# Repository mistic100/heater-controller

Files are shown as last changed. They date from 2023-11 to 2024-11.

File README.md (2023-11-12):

# heater controller

This is controller for electric heater with a control wire, widespread in France (Europe ?).



Inspired by [Jérôme Labidurie work](http://dinask.eu/hardware/filpilote/).

It can control two separate electric heaters with four orders (Confort, Éco, Hors gel, Arrêt) and one electric water tank (via controllable circuit beaker). It connects to your WiFi and has a nice web interface.

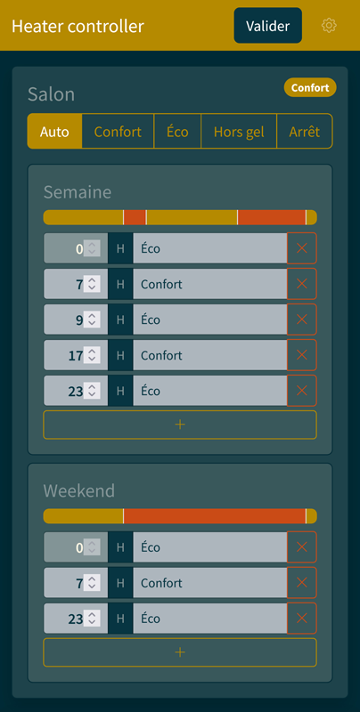
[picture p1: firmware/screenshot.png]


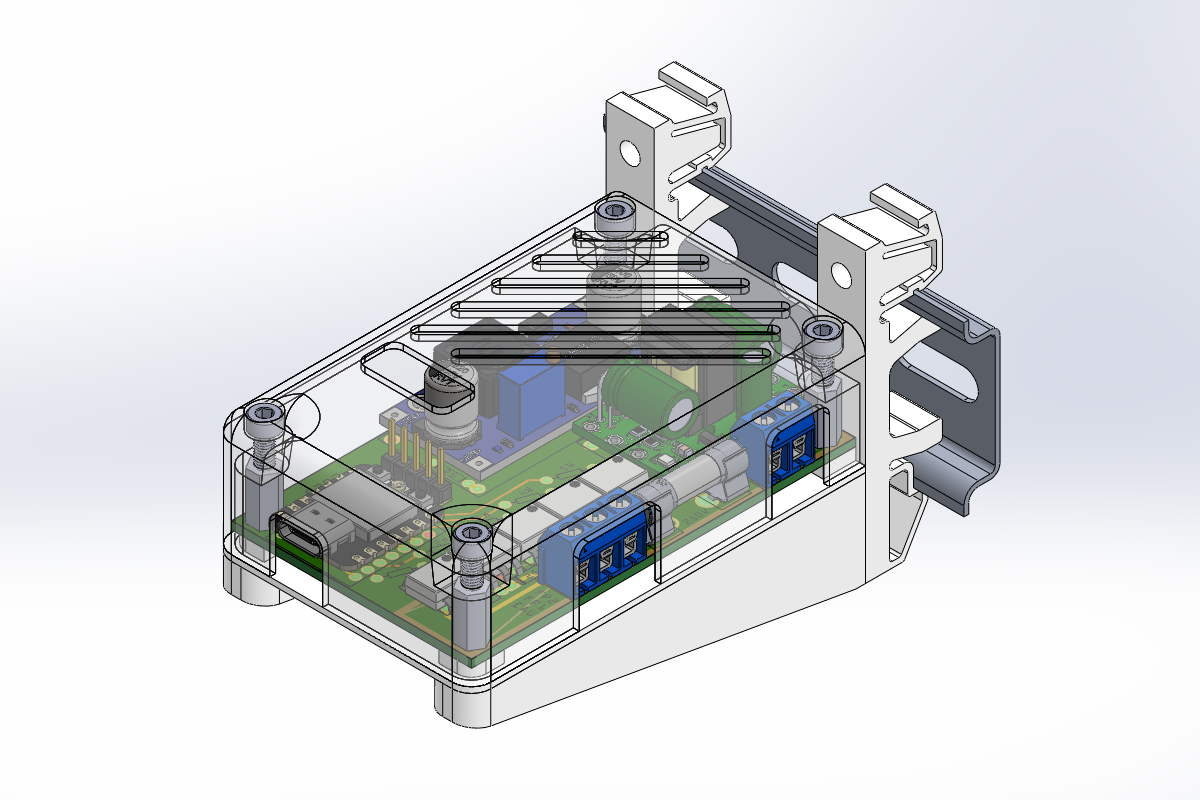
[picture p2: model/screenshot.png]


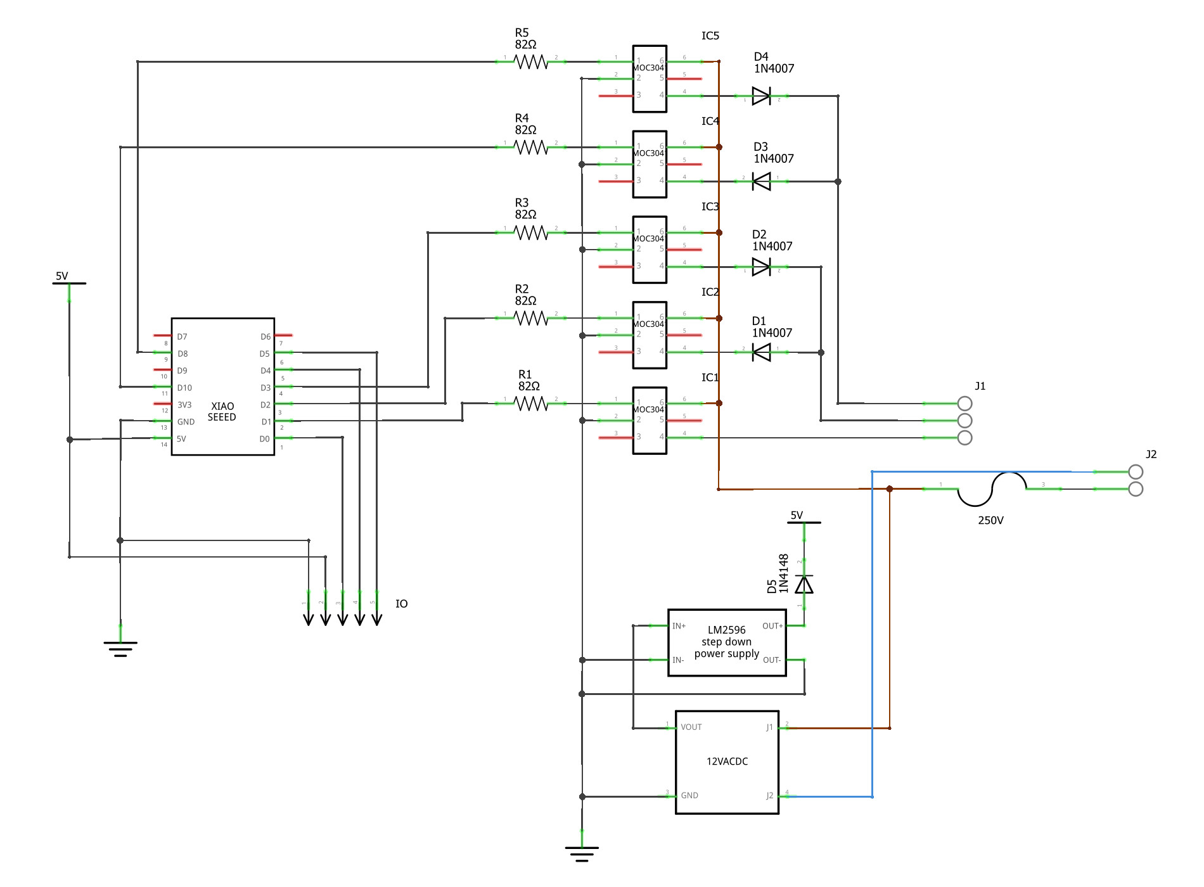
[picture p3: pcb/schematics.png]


## Hardware

- Seeduino Xiao ESP32C3
- mini 12V AC/DC converter
- LM2596 step down regulator
- 5x MOC3041 triac driver
- 4x 1N4007 diode
- 1x 1N4148 diode
- 5x resistors
- 250V fuse
- terminals
- M3 screws, spacers and heated inserts
- 3D printed case

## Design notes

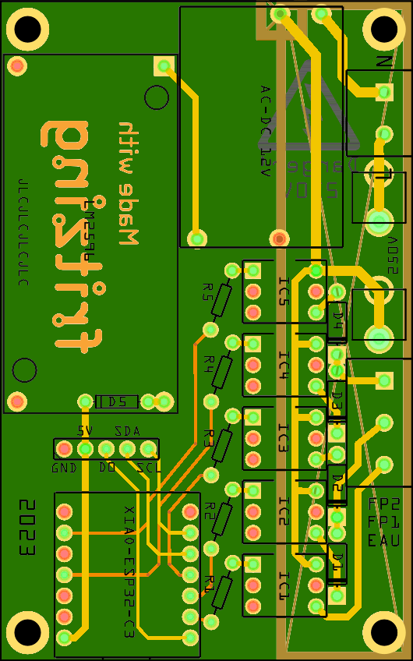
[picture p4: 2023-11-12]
model/pcb.png

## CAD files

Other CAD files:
model/_assembly.SLDASM
model/board.SLDASM
model/din clip.SLDPRT
model/box bottom.SLDPRT
model/Pin Header 1x5 TH Pitch 2.54mm.stp
model/support bottom.SLDPRT
model/din rail.SLDPRT
model/Symétriesupport bottom.SLDPRT
model/box top.SLDPRT
model/pcb.SLDPRT
model/spacer.SLDPRT
model/LM2596 DC-DC StepDown Converter v1.step
model/DIP 6 10_16.stp
model/DG306-5.0-03P-12-00AH.STEP
model/DG306-5.0-02P-12-00AH.STEP
model/Fuse Holder.STEP
model/Seeed Studio XIAO-ESP32-C3.step
model/ACDC100V_5VConverter.STEP
model/M3 x 0.5mm Thread 10mm LONG SOCKET HEAD CAP SCREW.STEP

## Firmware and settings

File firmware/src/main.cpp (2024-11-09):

#include <Arduino.h>
#include <ElegantOTA.h>
#include <LittleFS.h>
#include "constants.h"
#include "utils.hpp"
#include "Config.hpp"
#include "WifiServer.hpp"
#include "Controller.hpp"

Config config;
Controller ctrl(&config);
WifiServer server(&config, &ctrl);
bool ap_mode = false;

void setup()
{
    Serial.begin(115200);
    delay(2000);
    info("Start");

    if (!LittleFS.begin(false))
    {
        error("Failed to init LittleFS");
        return;
    }

    if (!config.loadAuth())
    {
        info("Create default auth file");
        config.saveAuth(AUTH_DEFAULT_USER, AUTH_DEFAULT_PASS);
    }

    if (!config.loadWifi())
    {
        ap_mode = true;
        server.initAP();
    }
    else
    {
        config.load();
        server.init();
        ctrl.init();
    }
}

void loop()
{
    if (!ap_mode)
    {
        ctrl.loop();
        ElegantOTA.loop();
    }
}

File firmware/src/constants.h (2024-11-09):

#pragma once

#define AP_SSID "AP-HEATER"
#define HOSTNAME "heater-ctrl"

#define AUTH_CONFIG_FILE "/auth.txt"
#define WIFI_CONFIG_FILE "/wifi.txt"
#define CONFIG_FILE "/config.json"

#define AUTH_DEFAULT_USER "admin"
#define AUTH_DEFAULT_PASS "admin"

#define WIFI_RETRIES 5
#define WIFI_RETRY_INTERVAL 5000

// https://github.com/nayarsystems/posix_tz_db/blob/master/zones.csv
#define TIMEZONE "CET-1CEST,M3.5.0,M10.5.0/3"
#define NTP_POOL "pool.ntp.org"

#define KEY_ZONE1 "zone1"
#define KEY_ZONE2 "zone2"
#define KEY_WATER "water"

#define UPDATE_INTERVAL 10 * 60 * 1000
#define PIN_WATER D1
#define PIN_FP1_POSITIVE D3
#define PIN_FP1_NEGATIVE D2
#define PIN_FP2_POSITIVE D8
#define PIN_FP2_NEGATIVE D10

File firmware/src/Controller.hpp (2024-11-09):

#pragma once

#include <ArduinoJson.h>

#include "constants.h"
#include "model.hpp"
#include "Config.hpp"

class Controller
{
private:
    Config *config;

    Mode mode_zone1 = OFF;
    Mode mode_zone2 = OFF;
    Mode mode_water = OFF;

    unsigned long previousMillis = 0;
    bool needsUpdate = false;

public:
    Controller(Config *config) : config(config)
    {
        pinMode(PIN_WATER, OUTPUT);
        pinMode(PIN_FP1_NEGATIVE, OUTPUT);
        pinMode(PIN_FP1_POSITIVE, OUTPUT);
        pinMode(PIN_FP2_NEGATIVE, OUTPUT);
        pinMode(PIN_FP2_POSITIVE, OUTPUT);
    }

    void init()
    {
        needsUpdate = true;
    }

    void loop()
    {
        unsigned long currentMillis = millis();
        if (needsUpdate || (currentMillis - previousMillis >= UPDATE_INTERVAL))
        {
            update();
            previousMillis = currentMillis;
            needsUpdate = false;
        }
    }

    void willUpdate()
    {
        needsUpdate = true;
    }

    void getStatus(Print* output) const
    {
        JsonDocument status;
        status[KEY_ZONE1] = modeToStr(mode_zone1);
        status[KEY_ZONE2] = modeToStr(mode_zone2);
        status[KEY_WATER] = modeToStr(mode_water);
        serializeJson(status, *output);
    }

private:
    void update()
    {
        struct tm time;
        getLocalTime(&time);

        info("Update zone 1");
        Zone zone1 = config->zone1();
        mode_zone1 = getMode(zone1, time);
        apply(PIN_FP1_POSITIVE, PIN_FP1_NEGATIVE, mode_zone1);

        info("Update zone 2");
        Zone zone2 = config->zone2();
        mode_zone2 = getMode(zone2, time);
        apply(PIN_FP2_POSITIVE, PIN_FP2_NEGATIVE, mode_zone2);

        info("Update water");
        Water water = config->water();
        mode_water = getMode(water, time);
        apply(PIN_WATER, mode_water);
    }

    const Mode getMode(const Zone &zone, const struct tm &time) const
    {
        debug("Mode", modeToStr(zone.mode));

        if (zone.mode == AUTO)
        {
            bool isWeekend = time.tm_wday == 0 || time.tm_wday == 6;
            auto timetable = isWeekend ? zone.weekend : zone.weekday;
            return getMode(timetable, time.tm_hour);
        }

        return zone.mode;
    }

    const Mode getMode(const Water &water, const struct tm &time) const
    {
        debug("Mode", modeToStr(water.mode));

        if (water.mode == AUTO)
        {
            return getMode(water.week, time.tm_hour);
        }

        return water.mode;
    }

    const Mode getMode(const std::vector<TimeItem> &timetable, int hour) const
    {
        for (size_t i = timetable.size() - 1; i >= 0; i--)
        {
            if (hour >= timetable[i].hour)
            {
                debug("Scheduled mode", modeToStr(timetable[i].mode));
                return timetable[i].mode;
            }
        }

        error("No suitable timetable found");
        return ON;
    }

    void apply(u8_t pin_positive, u8_t pin_negative, Mode mode)
    {
        switch (mode)
        {
        case ON:
            digitalWrite(pin_positive, LOW);
            digitalWrite(pin_negative, LOW);
            break;
        case ECO:
            digitalWrite(pin_positive, HIGH);
            digitalWrite(pin_negative, HIGH);
            break;
        case GEL:
            digitalWrite(pin_positive, LOW);
            digitalWrite(pin_negative, HIGH);
            break;
        case OFF:
            digitalWrite(pin_positive, HIGH);
            digitalWrite(pin_negative, LOW);
            break;
        default:
            error("Should not be there");
            digitalWrite(pin_positive, LOW);
            digitalWrite(pin_negative, LOW);
            break;
        }
    }

    void apply(u8_t pin, Mode mode)
    {
        switch (mode)
        {
        case ON:
            digitalWrite(pin, HIGH);
            break;
        case OFF:
            digitalWrite(pin, LOW);
            break;
        default:
            error("Should not be there");
            digitalWrite(pin, HIGH);
            break;
        }
    }
};

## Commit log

2023-10-30 Do not use json as main model
    # Liste des mots clés de titre de commit (version courte -> résultat long)
    # i <slug>-<num> -> Récupération de l'issue Jira (Issue #<slug>-<num> : <titre_de_lissue>)
    # t <titre> -> Technique : <titre>
    # f <titre> -> Fix : <titre>
    # ty <titre> -> Typo : <titre>
    # d <titre> -> Doc : <titre>
    # s <titre> -> Sécurité : <titre>
    # u <titre> -> UI : <titre>
    # c <titre> -> CI : <titre>
    # dr <titre> -> Draft: <titre>
    # [skip ci] en début de titre de commit permet de ne pas déclencher de build
    #
    # Chaque ligne de description ajouté sera préfixé automatiquement d'une puce.
    #
    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
2023-10-30 Add water heater
2023-11-11 Fix wiring
    [heater.fzz]
2023-11-23 fix: first range not tested
    [Controller.hpp]
